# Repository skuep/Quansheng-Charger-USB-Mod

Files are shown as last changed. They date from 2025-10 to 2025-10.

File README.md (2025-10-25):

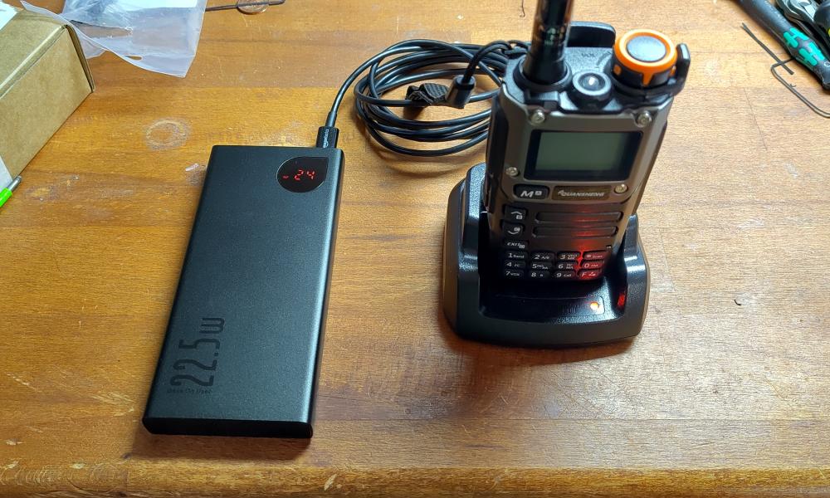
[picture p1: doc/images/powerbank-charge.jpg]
Quansheng USB Charging Cradle


# Quansheng Charger Modification for USB Type-C Input
This is a mod for the original Quansheng (UV-K5) charging cradle so you can charge your radio using via USB--C

# Order at JLCPCB
Use the production files in the kicad folder to directly order at JLCPCB.

- Upload [GERBER-quansheng-usb-charger.zip](kicad/quansheng-usb-charger/jlcpcb/production_files/GERBER-quansheng-usb-charger.zip?raw=true) to JLCPCB.
- Choose 1.6mm PCB thickness, LeadFree HASL
- Enable "PCB Assembly" with "Economic" type. Select "Tooling Holes Added by Customer"
- Press NEXT button
- Upload [BOM-quansheng-usb-charger.csv](kicad/quansheng-usb-charger/jlcpcb/production_files/BOM-quansheng-usb-charger.csv?raw=true) and [CPL-quansheng-usb-charger.csv](kicad/quansheng-usb-charger/jlcpcb/production_files/CPL-quansheng-usb-charger.csv?raw=true) files. 
- Press Continue for the Error message of some missing parts (It's okay). 
- **Make sure all parts are selected for placement** and Press Next
- Check Placement and Press Next
- Select Production Description (e.g. Smart Products and Accessories -> Charger)
- Save To Cart 

# Assemble
1. Buy a new Quansheng UV-K5 charging cradle from AliExpress, if you want to keep your current one
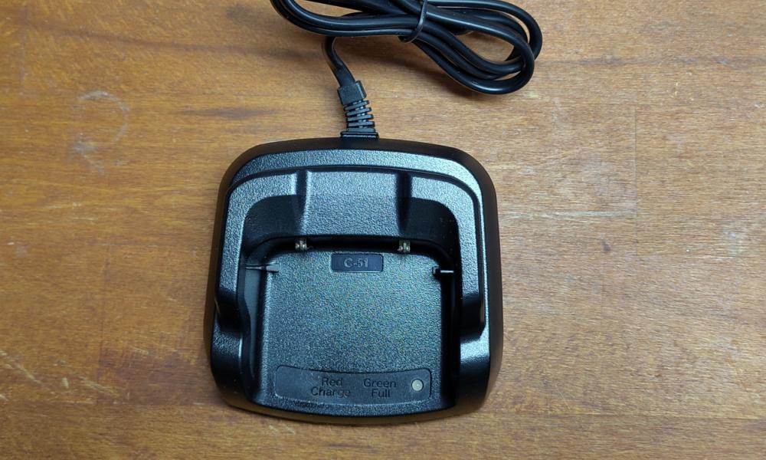
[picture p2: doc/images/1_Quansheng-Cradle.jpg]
  

2. Open up charging cradle
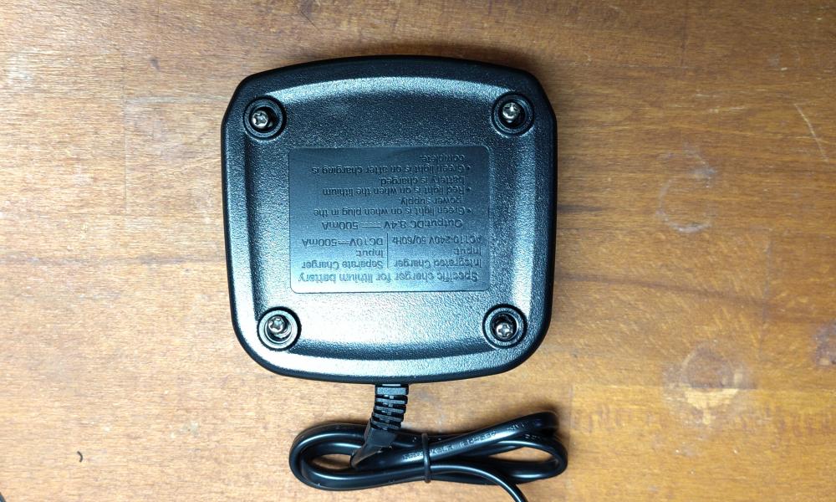
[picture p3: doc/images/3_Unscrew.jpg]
  

3. Remove the original PCB, slightly push one of the hooks to the side with your finger for easier release
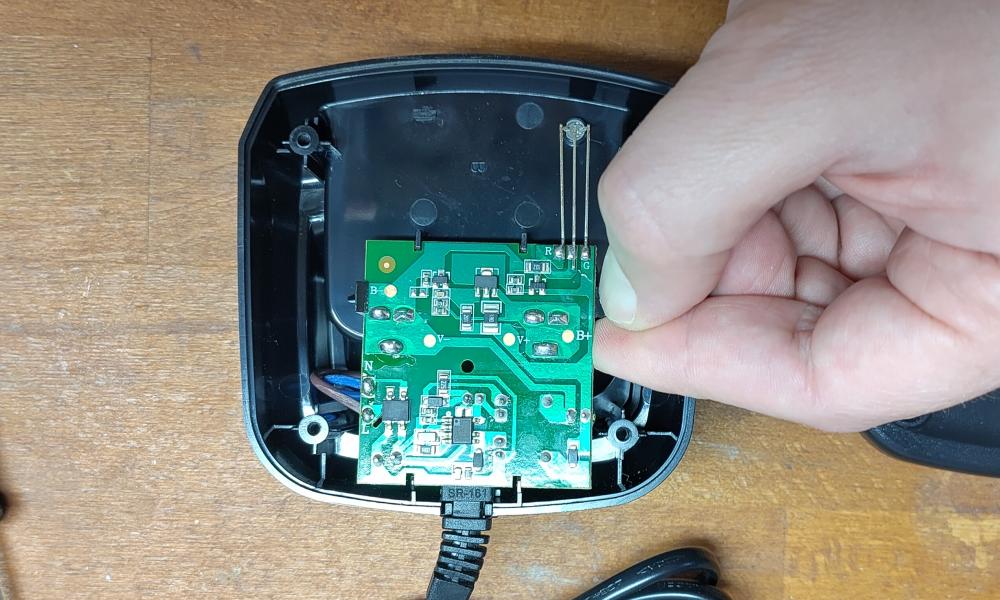
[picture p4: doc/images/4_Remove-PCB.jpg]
  

4. Desolder the two large spring contacts (3 solder joints each) and the 3-Pin LED at the bottom e.g. using desoldering wick.
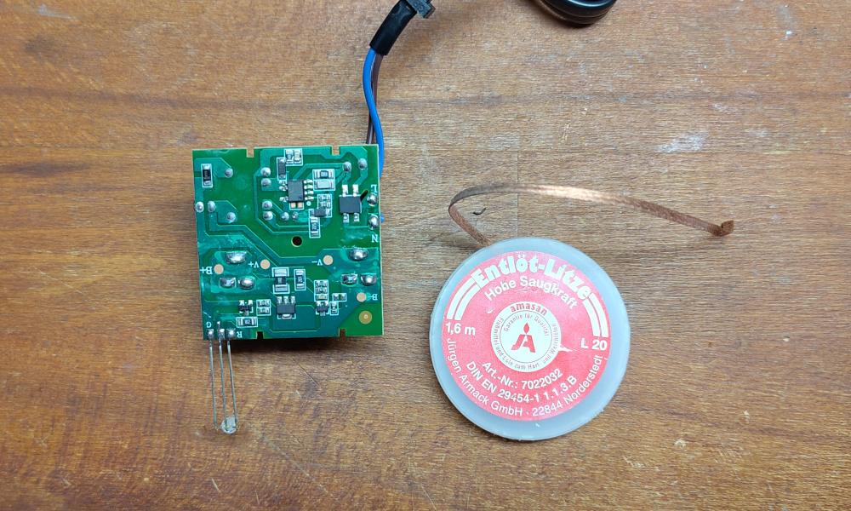
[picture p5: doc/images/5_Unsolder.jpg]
  
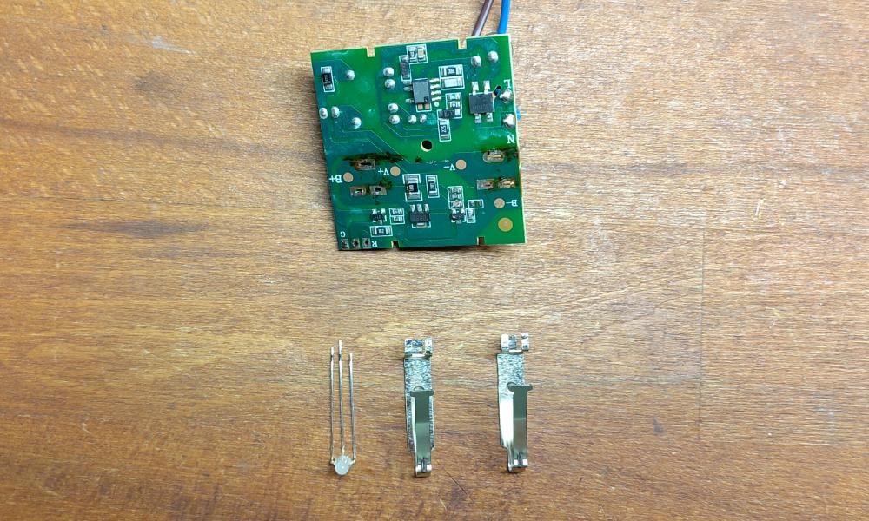
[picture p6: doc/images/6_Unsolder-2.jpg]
  

5. Get the freshly made Mod PCBs from JLCPCB
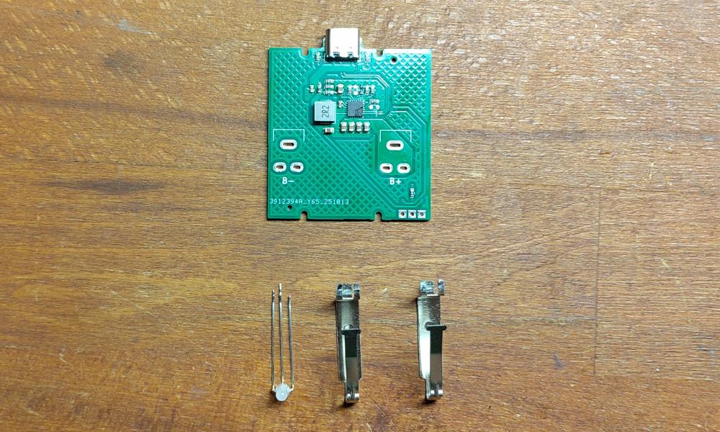
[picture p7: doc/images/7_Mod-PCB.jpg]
  

6. Solder in the spring contacts from one of the previous steps
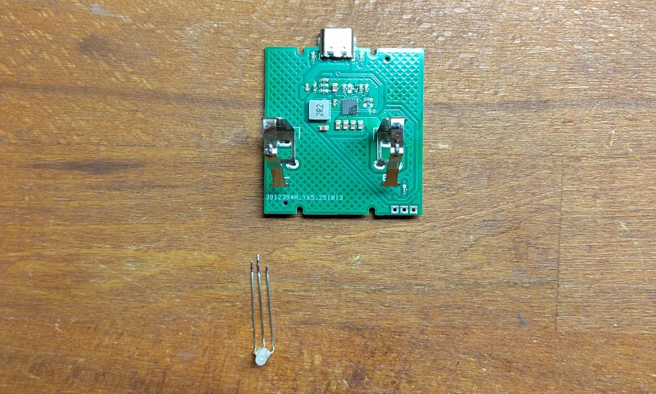
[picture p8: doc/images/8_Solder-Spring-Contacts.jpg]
  

7. Insert the blind-plug in the upper shell half. Either use the 3D printed one (see ``Blind-Plug.stl``) or modify the original one by cutting it.
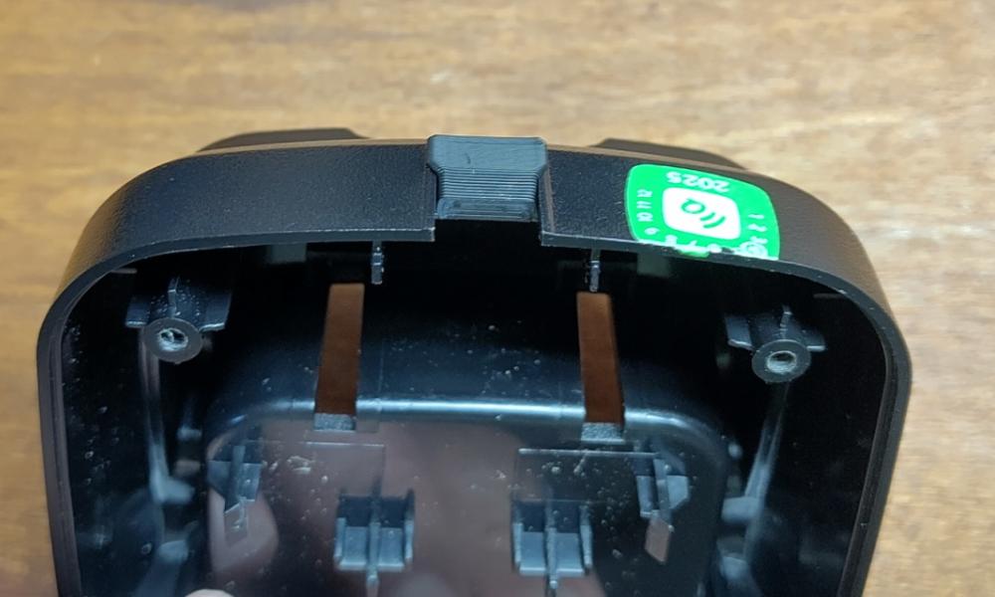
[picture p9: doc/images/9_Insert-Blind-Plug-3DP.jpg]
  
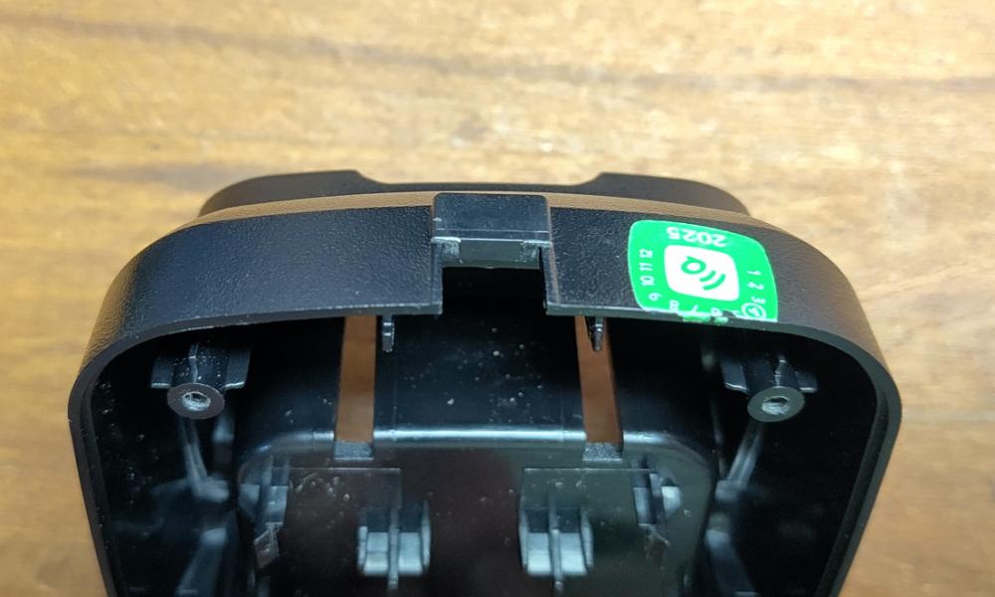
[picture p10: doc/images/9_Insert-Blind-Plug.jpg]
  

8. Feed in the spring contacts into their seating. Push down at the USB-C connector side until it is seated
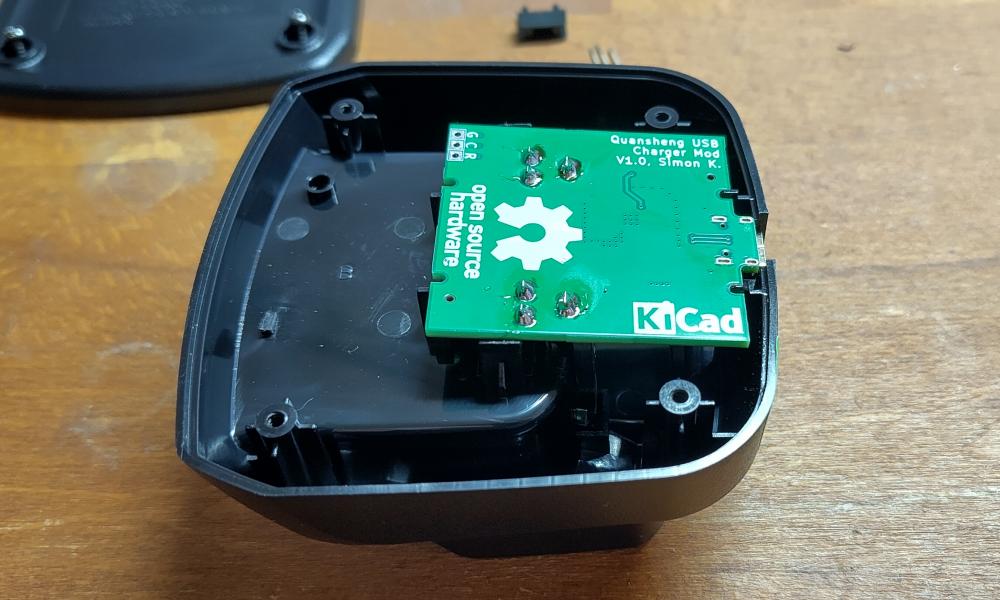
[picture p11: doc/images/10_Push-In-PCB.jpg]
  

9. Next, also push in the opposite side. Note that you might need to use a flathead screw-driver to help push the hook to the side a bit while pressing down.
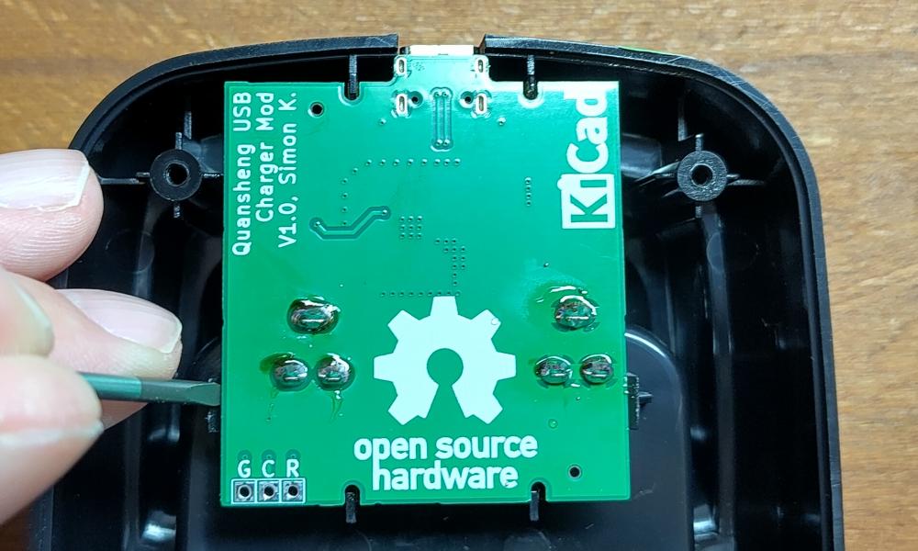
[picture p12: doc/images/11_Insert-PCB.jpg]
  

10. Lastly, put the LED in place and re-solder it.
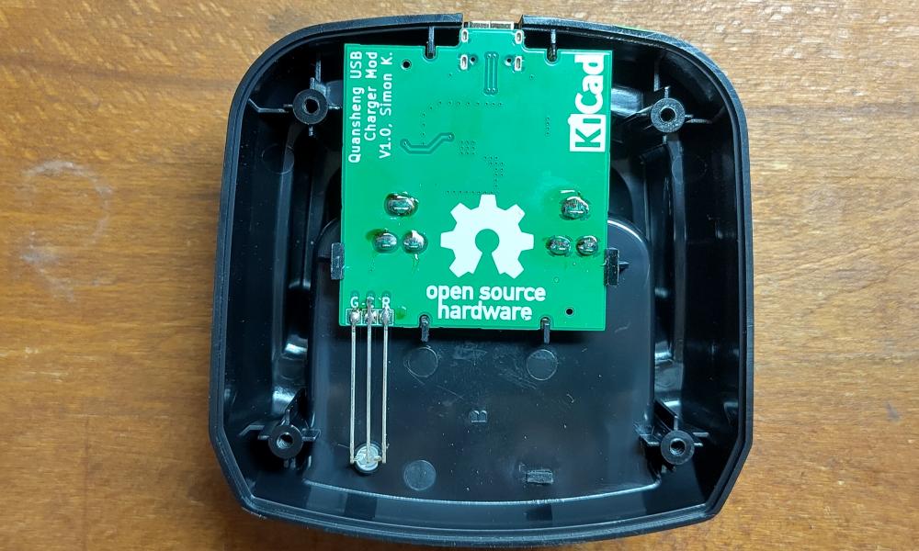
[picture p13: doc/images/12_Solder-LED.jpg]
  

11. Done! Test it and put the screws back in

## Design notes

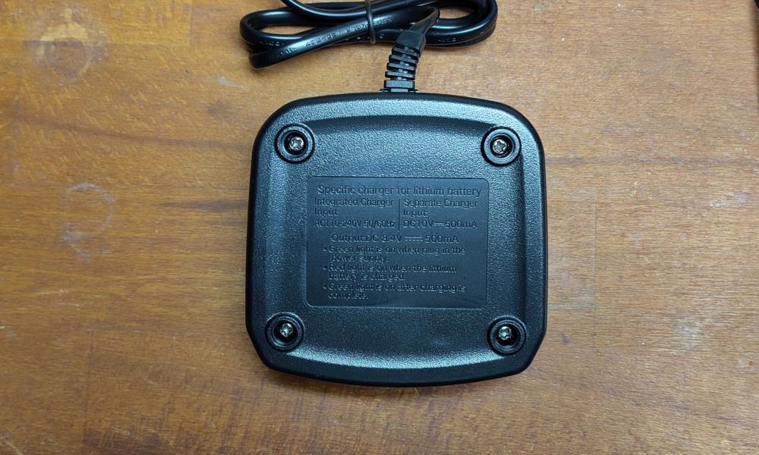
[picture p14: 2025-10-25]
doc/images/2_Bottom-Side.jpg

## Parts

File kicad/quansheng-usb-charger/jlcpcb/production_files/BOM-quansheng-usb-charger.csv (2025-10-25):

Comment | Designator | Footprint | LCSC
100n/25V | C1,C4 | C_0603_1608Metric | C14663
10u/25V | C2,C3,C7,C8 | C_0805_2012Metric | C15850
FXL0530-2R2-M | L1 | L_Sunlord_MWSA0518_5.4x5.2mm | C177247
1K | R5,R7 | R_0603_1608Metric | C21190
1R | R13,R14,R6 | R_0603_1608Metric | C22936
5.1K | R1,R2,R3 | R_0603_1608Metric | C23186
51K | R11 | R_0603_1608Metric | C23196
120K | R12,R17,R8 | R_0603_1608Metric | C25808
IP2326 | U1 | HVQFN-24-1EP_4x4mm_P0.5mm_EP2.5x2.5mm | C2832094
USB_C_Receptacle_USB2.0 | J1 | USB_C_Receptacle_GCT_USB4105-xx-A_16P_TopMnt_Horizontal | C2988369
22u/25V | C5,C6 | C_0805_2012Metric | C45783
BLM18KG121TN1D | FB1 | L_0603_1608Metric | C85831
NC | R4 | R_0603_1608Metric
BAT- | TP2 | SPRING-CONTACT
NC | R9 | R_0603_1608Metric
BAT+ | TP1 | SPRING-CONTACT
NC | R10 | R_0603_1608Metric
LEDG | TP3 | TestPoint_THTPad_2.0x2.0mm_Drill1.0mm
LEDCOM | TP4 | TestPoint_THTPad_2.0x2.0mm_Drill1.0mm
LEDR | TP5 | TestPoint_THTPad_2.0x2.0mm_Drill1.0mm
ToolingHole | H2 | TOOLING-HOLE
ToolingHole | H1 | TOOLING-HOLE
NC | R16 | R_0603_1608Metric
NC | R15 | R_0603_1608Metric
ISET | JP1 | SolderJumper-2_P1.3mm_Open_TrianglePad1.0x1.5mm

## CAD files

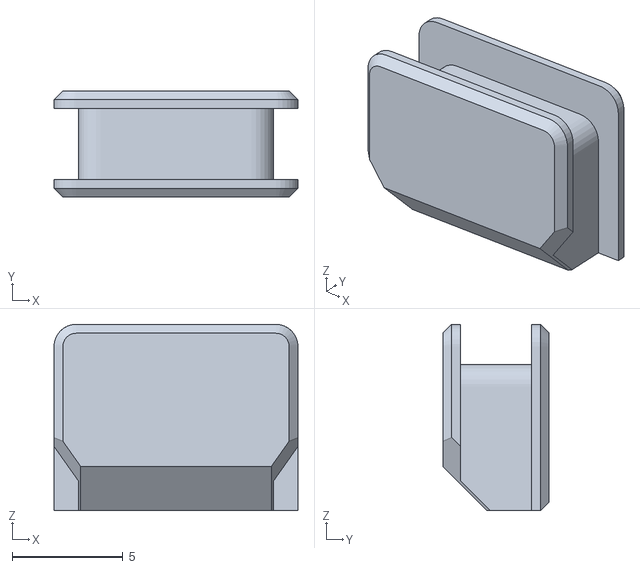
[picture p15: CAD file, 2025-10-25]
Blind-Plug.stl
11.0 x 4.80 x 8.40

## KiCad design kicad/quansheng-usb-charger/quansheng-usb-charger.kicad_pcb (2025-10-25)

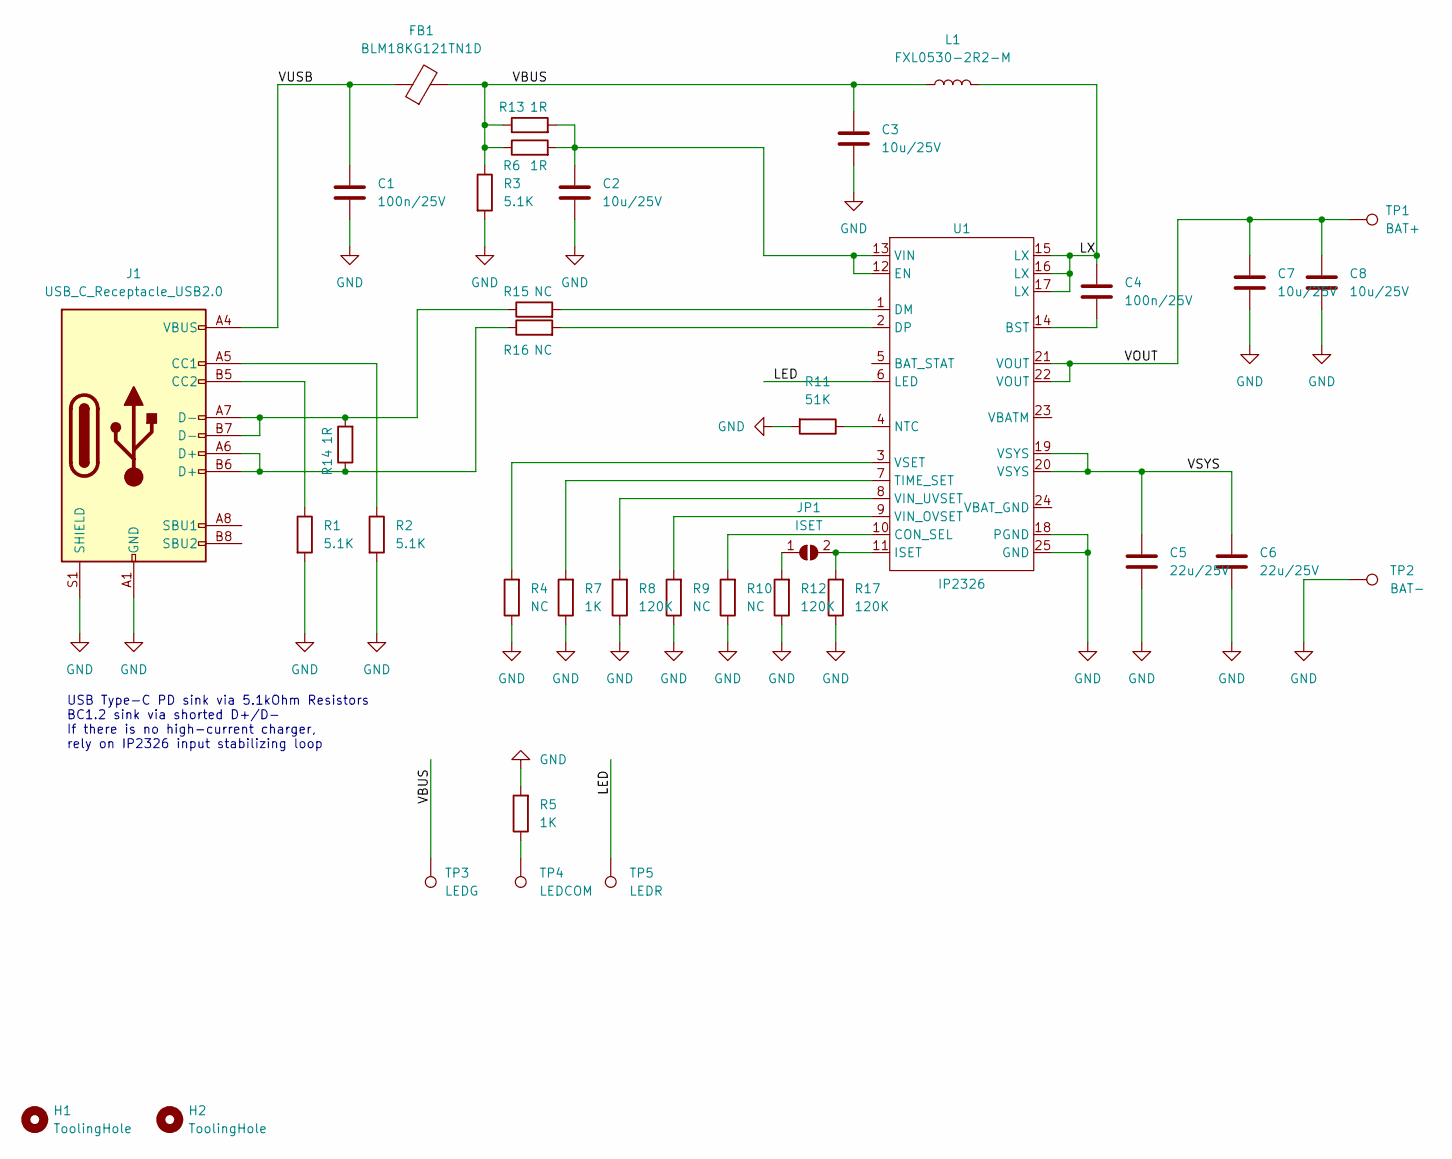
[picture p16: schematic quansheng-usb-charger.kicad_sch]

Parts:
C1, C4: 100n/25V; C_0603_1608Metric; LCSC C14663
C2, C3, C7, C8: 10u/25V; C_0805_2012Metric; LCSC C15850
C5, C6: 22u/25V; C_0805_2012Metric; LCSC C45783
FB1: BLM18KG121TN1D; L_0603_1608Metric; LCSC C85831
H1, H2: ToolingHole; TOOLING-HOLE
J1: USB_C_Receptacle_USB2.0; USB_C_Receptacle_GCT_USB4105-xx-A_16P_TopMnt_Horizontal; LCSC C2988369
JP1: ISET; SolderJumper-2_P1.3mm_Open_TrianglePad1.0x1.5mm
L1: FXL0530-2R2-M; L_Sunlord_MWSA0518_5.4x5.2mm; LCSC C177247
R1, R2, R3: 5.1K; R_0603_1608Metric; LCSC C23186
R4, R9, R10, R15, R16: NC; R_0603_1608Metric
R5, R7: 1K; R_0603_1608Metric; LCSC C21190
R6, R13, R14: 1R; R_0603_1608Metric; LCSC C22936
R8, R12, R17: 120K; R_0603_1608Metric; LCSC C25808
R11: 51K; R_0603_1608Metric; LCSC C23196
TP1: BAT+; SPRING-CONTACT
TP2: BAT-; SPRING-CONTACT
TP3: LEDG; TestPoint_THTPad_2.0x2.0mm_Drill1.0mm
TP4: LEDCOM; TestPoint_THTPad_2.0x2.0mm_Drill1.0mm
TP5: LEDR; TestPoint_THTPad_2.0x2.0mm_Drill1.0mm
U1: IP2326; HVQFN-24-1EP_4x4mm_P0.5mm_EP2.5x2.5mm; LCSC C2832094

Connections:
/LED: TP5.1, U1.6 (LED)
/LX: C4.2, L1.2, U1.15 (LX), U1.16 (LX), U1.17 (LX)
/VBUS: C3.1, FB1.2, L1.1, R3.1, R6.1, R13.1, TP3.1
/VOUT: C7.1, C8.1, TP1.1, U1.21 (VOUT), U1.22 (VOUT)
/VSYS: C5.1, C6.1, U1.19 (VSYS), U1.20 (VSYS)
/VUSB: C1.2, FB1.1, J1.A4 (VBUS), J1.A9 (VBUS), J1.B4 (VBUS), J1.B9 (VBUS)
GND: C1.1, C2.2, C3.2, C5.2, C6.2, C7.2, C8.2, J1.A1 (GND), J1.A12 (GND), J1.B1 (GND), J1.B12 (GND), J1.S1 (SHIELD), R1.2, R2.2, R3.2, R4.1, R5.2, R7.1, R8.1, R9.1, R10.1, R11.2, R12.1, R17.1, TP2.1, U1.18 (PGND), U1.25 (GND)
unnamed: C2.1, R6.2, R13.2, U1.12 (EN), U1.13 (VIN)
unnamed: C4.1, U1.14 (BST)
unnamed: J1.A5 (CC1), R2.1
unnamed: J1.A6 (D+), J1.B6 (D+), R14.1, R16.1
unnamed: J1.A7 (D-), J1.B7 (D-), R14.2, R15.1
unnamed: J1.B5 (CC2), R1.1
unnamed: R4.2, U1.3 (VSET)
unnamed: R5.1, TP4.1
unnamed: R7.2, U1.7 (TIME_SET)
unnamed: R8.2, U1.8 (VIN_UVSET)
unnamed: R9.2, U1.9 (VIN_OVSET)
unnamed: R10.2, U1.10 (CON_SEL)
unnamed: R11.1, U1.4 (NTC)
unnamed: JP1.1 (A), R12.2
unnamed: R15.2, U1.1 (DM)
unnamed: R16.2, U1.2 (DP)
unnamed: JP1.2 (B), R17.2, U1.11 (ISET)

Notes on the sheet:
USB Type-C PD sink via 5.1kOhm Resistors BC1.2 sink via shorted D+/D- If there is no high-current charger, rely on IP2326 input stabilizing loop

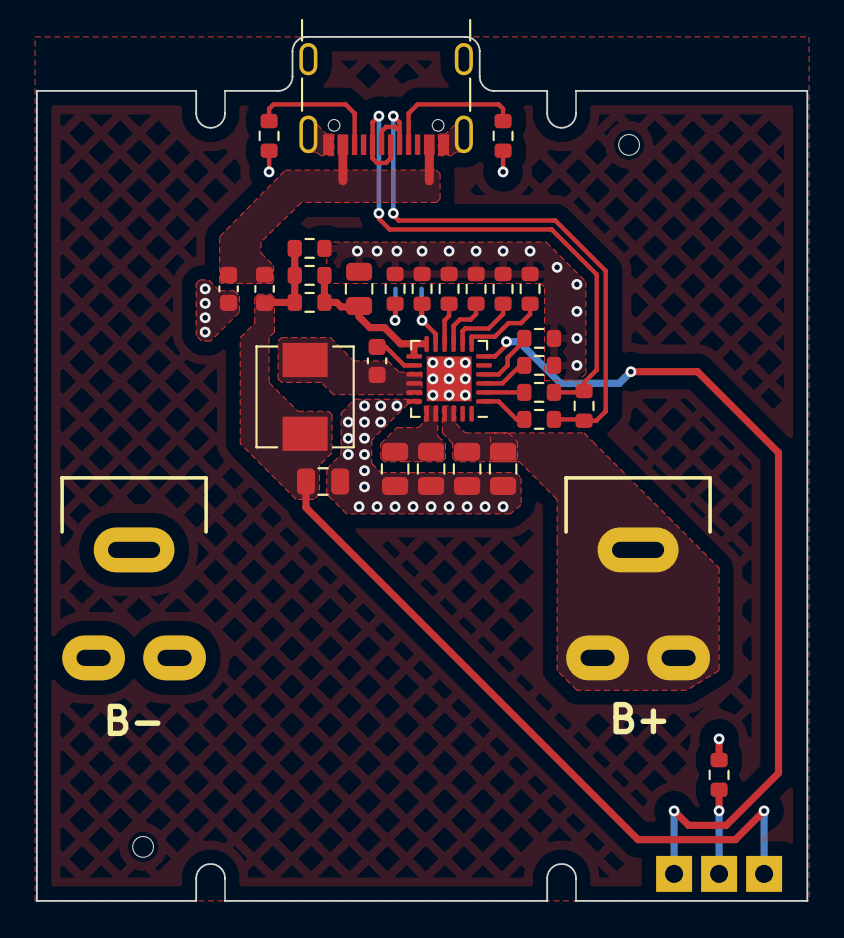
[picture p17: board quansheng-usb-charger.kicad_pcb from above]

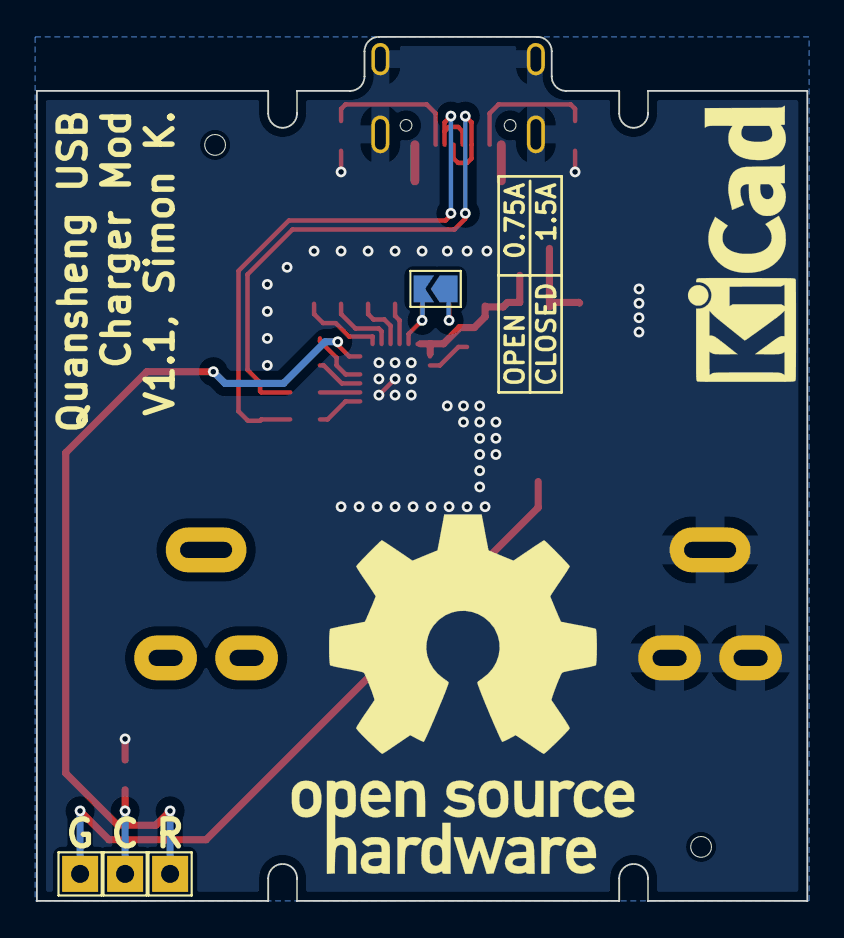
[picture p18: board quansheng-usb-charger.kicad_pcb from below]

Board: 2 copper layers, 42.8 x 48.0 mm, 37 parts (4 on the bottom side), 24 nets.

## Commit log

2025-10-12 Add JLCPCB files and README
    [BOM-quansheng-usb-charger.csv, quansheng-usb-charger.kicad_pcb, quansheng-usb-charger.kicad_sch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]
2025-10-12 Improve mechanical fit
    [BOM-quansheng-usb-charger.csv, quansheng-usb-charger.kicad_pcb, quansheng-usb-charger.kicad_sch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]
2025-10-12 Silkscreen adjustments
    [quansheng-usb-charger.kicad_pcb]
2025-10-12 Add Tooling Holes
    [quansheng-usb-charger.kicad_pcb, quansheng-usb-charger.kicad_sch]
2025-10-25 Don't use the built-in USB AFC standard
    [BOM-quansheng-usb-charger.csv, quansheng-usb-charger.kicad_pcb, quansheng-usb-charger.kicad_sch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]
2025-10-25 Add jumper pad for optional 1.5A charging current
    [BOM-quansheng-usb-charger.csv, quansheng-usb-charger.kicad_pcb, quansheng-usb-charger.kicad_sch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]
2025-10-25 Add 3D printed blind plug for back
    [Blind-Plug.stl]
